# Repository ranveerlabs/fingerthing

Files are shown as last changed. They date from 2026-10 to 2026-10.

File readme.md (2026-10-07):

# fingerthing

i wanted touchid but too broke for a maccc

USB fingerprint security key for passkeys and 2FA. RP2350, a 3.3 V R503 sensor
and [pico-fido2](https://github.com/librekeys/pico-fido2) firmware.

fingerthing board front

## why

I want fingerprint approval for my npm account and other FIDO2 sites, using
the same key across laptops. Linux, Windows, macOS and
[FreeBSD](host/freebsd/readme.md) are targets. sudo through PAM is another target.

## the key

The sensor matches on-chip and sends the result over UART. A fresh match
approves user presence. FIDO PIN handles verification and allows button
fallback. The fingerprint never sets UV, and UART matches can be spoofed.

Pico 2 comes first for bring-up. The custom board has USB-C, switched sensor
power, a separate presence button, BOOTSEL, a status LED and SWD pads.

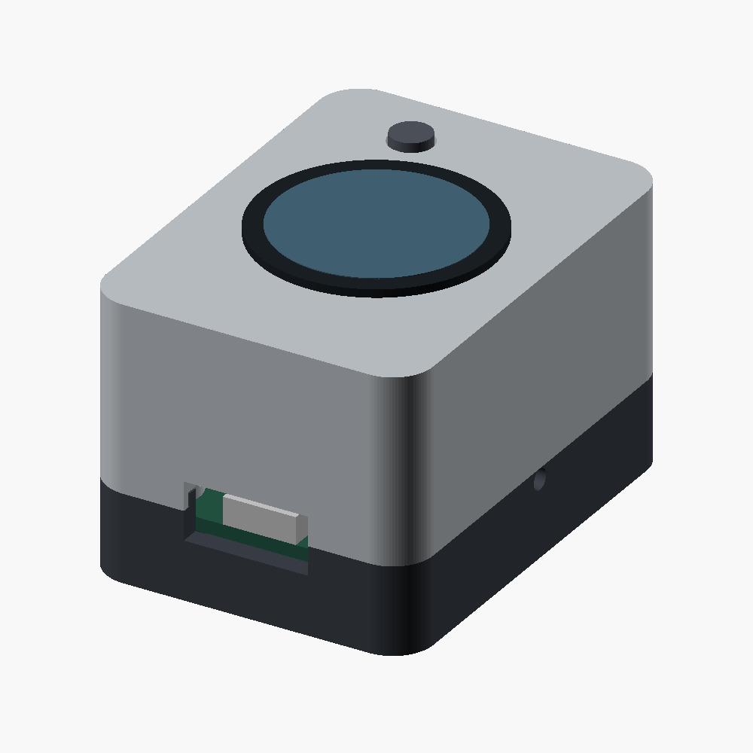
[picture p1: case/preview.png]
fingerthing case design


## build and test

The [firmware guide](firmware/Readme.md) lists the tools and image paths.
Use a dedicated development board. Signing firmware locks OTP storage on
first boot, and reflashing cannot undo that.

```sh
bash firmware/test.sh
bash firmware/build.sh button
bash firmware/build.sh sensor
bash firmware/build.sh pcb
```

[Parts](docs/BOM.md) and [bring-up steps](docs/bringup.md) cover wiring and
enrollment. [Hardware notes](hardware/DESIGN.md) cover the board and sensor.

## status

The 34 x 48 mm four-layer PCB is routed. ERC, DRC and schematic parity pass
with no violations or unconnected items. Firmware builds and host tests pass.
Nothing has been tested on hardware. npm, sudo and OS compatibility remain
unverified. USB power, secure boot and [case fit](case/ReadMe.md) still need
physical tests. The PCB and case are drafts.

Changes and test results are in the [journal](JOURNAL.md).

## license

[CERN-OHL-S-2.0](LICENSE). Firmware is [AGPL-3.0-only](firmware/LICENSE),
including the pico-fido2 patches. Third-party files retain their own licenses :p

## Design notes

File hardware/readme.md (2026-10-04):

# hardware

[Build plan](DESIGN.md) · [KiCad draft](pcb/Readme.md)
Pico 2 bring-up first. The custom board is not ready to order.

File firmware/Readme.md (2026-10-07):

# firmware

[librekeys/pico-fido2](https://github.com/librekeys/pico-fido2) on Pico 2.
Pinned sources. Git, CMake 3.24+, Make, ARM GCC with Newlib, native C compiler,
Python 3. Pico SDK and picotool use 2.3.1. Each configure clears the CMake cache
so an older SDK cannot remain selected. UF2 paths stay the same.

After building all three signing images, `python3 firmware/tests/seal.py` uses
OpenSSL and picotool to check offline signing with a temporary test key. It
also checks that changing application bytes fails verification. The temporary
key and images are removed. This does not provision OTP or enable secure boot.

Supply your own secp256k1 PEM key for a signed build:

```sh
SIGNING_KEY=/absolute/path/private.pem bash firmware/build.sh pcb
```

All modes accept it. Outputs go to the usual directory with `-signed` appended,
such as `.build/pcb-signed/pico_fido2.uf2`. The SDK also creates an OTP JSON plan
containing the public-key hash and boot flags. Building never applies that plan.
Keep the private key outside the checkout and back it up. Fuse provisioning,
signed updates and recovery must be checked on a dedicated A4 board first.
Check a built image against its key with:

```sh
python3 firmware/tests/signed.py /absolute/path/private.pem .build/pcb-signed/pico_fido2.uf2
```

```sh
bash firmware/build.sh
bash firmware/build.sh sensor
bash firmware/build.sh pcb
bash firmware/build.sh enroll
bash firmware/build.sh enroll-pcb
```

UF2: `.build/pico2/pico_fido2.uf2` or `.build/sensor/pico_fido2.uf2`.
The custom board build is `.build/pcb/pico_fido2.uf2`. It uses an active-low
button on GP6 with a 20 ms debounce. BOOTSEL stays available for recovery.
GP8 powers the sensor for each approval attempt and turns it off afterward.
GP4 and GP5 return to inputs without pulls before power-off. The Pico 2 sensor
build leaves power wiring unchanged. Both wait 250 ms before enabling UART,
with cancellation and PIN fallback available during startup.
BOOTSEL while plugging in, then copy the UF2. Use a dedicated development board:
upstream writes and locks OTP keys on first boot. Reflashing cannot undo this.

Flash writes stop the device if the other core cannot be paused or resumed
after five attempts. Both erase paths mask interrupts. This avoids proceeding
after a failed handshake. Reset is required after that failure, and writes
already completed cannot be undone.

Button: fresh press and release. Sensor: fresh match in slot 0, one attempt per
request. Button fallback requires a verified PIN for that request. Both time out
after 30 seconds. Fingerprint approval never sets UV. OTP, OATH and debug output
are disabled. Secure boot is not enabled.

The inherited USB rescue app is unregistered. Its host commands cannot change
boot fuses, reboot into BOOTSEL or sign with the device rescue key. Recovery
uses the physical BOOTSEL control. OTP key initialization on first boot remains.

The signing builds declare 100 mA USB power. Actual draw and USB suspend are
unverified, see [power](../hardware/power.md).

The separate [power probe](power/Readme.md) builds with `bash firmware/build.sh power`.

Approval starts only while USB is configured and awake. Suspend, disconnect or
reconfiguration cancels pending button and fingerprint approval, including PIN
fallback. Resuming does not clear that cancellation. Request cleanup turns off
the PCB sensor. MCU sleep and physical suspend timing remain unverified.

R503: 3.3V and GND, sensor RX to GP4, TX to GP5. UART1, 57600 baud.
Enrollment: flash `.build/enroll/enroll.uf2` with BOOTSEL, open its USB serial
port, type `e`, then `y`. Lift and scan the same finger twice. Esc cancels.
This development image replaces slot 0 and has a 60-second timeout. Flash the
sensor firmware afterward. Use it before storing credentials. Enrollment has no FIDO code. Signing firmware has no enrollment command.

For the switched PCB, use `.build/enroll-pcb/enroll.uf2`, then the `pcb` signing
image. Enrollment powers the sensor only after `y` and turns it off when the
attempt ends. The plain `enroll` image does not control GP8.

Suspend, disconnect or reconfiguration cancels the pending enrollment and its
confirmation prompt. Resume does not clear it. Start again with `e`, then `y`.
Closing the serial connection's DTR line cancels it too.
Cancellation cannot undo a store command already sent, so slot 0 may have changed
even if the image reports failure.

UART matches can be spoofed. Enrollment has not been tested on hardware.

Builds and host tests pass. No hardware, npm or FreeBSD test yet.

## license

[AGPL-3.0-only](LICENSE). Upstream firmware and its dependencies retain their
own license notices.

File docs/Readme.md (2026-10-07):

# docs

[Parts](BOM.md) · [bring-up](bringup.md) · [hardware](../hardware/DESIGN.md) · [journal](../JOURNAL.md)

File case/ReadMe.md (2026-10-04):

# case

case

Rounded two-piece shell, USB-C at the front, screws underneath. The body is
39.4 x 53.4 x 33 mm around the 34 x 48 mm PCB. The sensor and button project
above it. [immurok](https://github.com/immurok/hardware) was a packaging reference.

[source](fingerthing.scad) and [parts](parts/) use millimetres. OpenSCAD 2021.01
exports the base upright, lid upside down and button upright:

```sh
for part in base lid button; do
    openscad -D "part=\"$part\"" --export-format binstl -o "case/parts/$part.stl" case/fingerthing.scad
done
```

The board sits 7 mm above the bottom. Four M2.5 x 10 screws pass through its
mounting holes into nuts in the lid. Nut pockets are 5.3 mm across flats and
2.4 mm deep. Screw head recesses are 5.2 mm wide and 2.4 mm deep. Use hardware
that fits these pockets, without washers against components.

Fit the sensor through the 25.5 mm opening and secure it with its supplied nut.
Insert the button from inside the lid, then the four nuts. Connect the sensor
cable before seating the board on the base supports and closing the shell.
BOOTSEL and SWD require opening the case. A side hole faces the status LED.

The [documented R503](../hardware/sensor.md) is 28 mm wide and 19 mm tall.
Its flange and nut are only approximate in the assembly view. The PCB and
component blocks in that view are clearance guides, not complete board models.

The three meshes are closed single pieces. Geometry checks cover the shell
joint, button at rest and 0.6 mm down, sensor opening and the board guides.
These checks do not prove that the supplied module, cable or USB plug fits.
Measure those before printing. Print a fit sample before committing to the shell.

`sensor_hole`, `fit`, `pcb_z` and `button_gap` adjust the fit. The switch's
[specified height](https://www.we-online.com/components/products/datasheet/434133025816.pdf)
is 2.5 mm. The default button gap is 0.35 mm. Check that it releases fully and
does not preload the switch before storing credentials. Print tolerances and
button travel still need a physical check.

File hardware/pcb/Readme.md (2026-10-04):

# pcb

KiCad 10. 34 x 48 mm, four layers, rounded corners. RP2350A, USB-C, R503 header,
GP6 presence button and rear SWD connector. All nets are routed. ERC, DRC and
board/schematic parity pass with no exclusions.

USB targets 90 ohms on JLC04161H-7628. The coupled section uses 0.235 mm traces,
0.15 mm spacing and 0.25 mm clearance to the ground fill. JLCPCB's calculator
returned 0.2347 mm for those inputs on 2026-10-04.

Copper and dielectric thicknesses follow that stackup: 0.035 mm outer copper,
0.0152 mm inner copper, 0.2104 mm prepreg and a 1.065 mm core. Solder-mask and
material-property fields remain nominal. Connector joins and ESD fan-out are
not fully coupled. Final fabrication review and hardware testing remain.

J1 is JAE DX07S016JA1R1500. The local KiCad footprint grounds both shell
reinforcement pads and removes the edge silk markers. Flash, crystal and core
regulator routing come from Raspberry Pi's RP2350A R4/S1 reference. C20 adds a
100 nF VBUS bypass beside the ESD protector's supply via.

R503 cable fit and the enclosure are not confirmed. Do not order this yet.
`bash hardware/check.sh` runs ERC and DRC with KiCad's standard libraries installed.

[BOM](bom.csv): 47 fitted components. R1 is DNP. U2 is AP2112K-3.3TRG1,
with C1 and C5 beside its input and output. Suspend handling and current
measurements remain, see [power](../power.md).

U5 is TPS22919DCKR. GP8 switches both R503 supplies. C21 bypasses the input,
C22 bypasses the output, R15 pulls ON down and R16 pulls sensor RX up to the
switched rail. The `pcb` and `enroll-pcb` images control the switch, with physical
power and backfeed tests still pending.
The UART pull-up branch uses In1.Cu below the USB routing.

The [local switch symbol](fingerthing.kicad_sym) comes from KiCad's
[Power_Management library](https://gitlab.com/kicad/libraries/kicad-symbols/-/blob/master/Power_Management.kicad_sym).
QOD has a passive pin type because TI specifies tying it to OUT. [license](LICENSE.kicad)

[reference](https://datasheets.raspberrypi.com/rp2350/Minimal-KiCAD.zip) · [license](LICENSE.raspberrypi)

[USB footprint](https://gitlab.com/kicad/libraries/kicad-footprints/-/blob/master/Connector_USB.pretty/USB_C_Receptacle_JAE_DX07S016JA1R1500.kicad_mod) · [license](LICENSE.kicad)

[impedance calculator](https://jlcpcb.com/pcb-impedance-calculator) · [stackup](https://jlcpcb.com/impedance) · [ESD layout](https://www.st.com/resource/en/datasheet/usblc6-2.pdf)

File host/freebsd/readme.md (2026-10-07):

# FreeBSD

Target: npm 2FA in Firefox, using the same USB firmware. Not tested yet.

The upstream firmware uses USB ID `1d50:619b`. Check with `usbconfig` before
installing the rule. It grants the `u2f` group access to matching `uhid` and
`hidraw` devices.

As root, from the repo:

```sh
pkg install firefox libfido2 u2f-devd
pw groupmod u2f -m YOUR_USER
install -m 644 host/freebsd/fingerthing.conf /usr/local/etc/devd/fingerthing.conf
service devd restart
```

Replace `YOUR_USER`, log out and back in, then reconnect the key. Run
`fido2-token -L` as that user. Test enrollment, sign-in and reconnect in Firefox
before trying npm. Record the FreeBSD, Firefox and firmware versions.

If the key is missing from the list, inspect its device node and permissions.
Don't grant access to every USB device or run the browser as root.

Based on FreeBSD's [u2f-devd rules](https://github.com/freebsd/freebsd-ports/tree/main/security/u2f-devd).
[libfido2](https://github.com/Yubico/libfido2/blob/main/src/hid_freebsd.c)
prefers `hidraw`, then falls back to `uhid`. FreeBSD's
[HID bus](https://github.com/freebsd/freebsd-src/blob/main/sys/dev/hid/hidbus.c)
reports the vendor and product IDs used by this rule.

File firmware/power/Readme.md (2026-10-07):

# power probe

```sh
bash firmware/build.sh power
```

Flash `.build/power/power.uf2` on a dedicated Pico 2 before storing credentials.
It replaces the running firmware. It has USB serial, no FIDO code and no OTP
provisioning. Reflashing does not undo OTP locks from an earlier signing image.
First measure with the sensor disconnected.

All images pin Pico SDK and picotool 2.3.1.
On USB suspend it switches the system and peripheral clocks to the crystal
reference, turns off PLL_SYS and sleeps until an interrupt. USB clocks and the
timer remain enabled. Resume restores the system clock.
The suspend snapshot, sensor switch and clock transition now share the same
IRQ mask as the sleep decision. This closes a window that could leave PLL_SYS
running while the probe slept. Host tests inject suspend at that boundary.

GP8 starts low and goes high only while USB is configured and awake. It drives
the ON input of the [sensor switch](../../hardware/power.md#sensor-switch),
not the sensor supply. GP4, GP5 and GP7 stay inputs with no pulls. This image
sends no UART commands.

Open USB serial and send `?`. The reply reports the configured system frequency
in Hz, not a measurement. Trigger actual USB bus suspend, then resume and send
`?` again. Check that serial returns without a reset or re-enumeration.

Measure VBUS current with a low-burden probe that preserves USB data. Capture
suspend entry and resume. Check the 2.5 mA suspend limit and 7 ms transition
in [the power notes](../../hardware/power.md). A sleeping computer alone does
not prove its USB port suspended this device.

The SDK serial descriptor declares 250 mA. This is a budget, not measured draw.
The image builds with warnings treated as errors. No physical power or wake
test yet. The switch is in the draft PCB. Signing firmware controls it per request.

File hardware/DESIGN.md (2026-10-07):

# hardware

Pico 2 for bring-up. Get registration and sign-in working with pico-fido2 and the
button before adding a fingerprint sensor. npm is the first real-service test.

## sensor

Use the 3.3 V R503 variant in [the sensor notes](sensor.md). Match on the module,
send the result over UART. Confirm the supplier's variant and cable before ordering.

A fresh match can gate user presence. It must not set FIDO's UV flag by itself.
Keep the upstream PIN path. Fingerprint UV needs enrollment authorization,
retry limits, reset handling and CTAP integration. PIN fallback does not prevent
someone injecting a fake match on the UART wires.

## board

- RP2350A, 12 MHz crystal, QSPI flash. Start from Raspberry Pi's reference circuit.
- USB-C, separate 5.1k CC pull-downs, ESD protection, 90 ohm differential routing.
- 3.3 V supply plus the RP2350 core regulator circuit and reference decoupling.
- Sensor connector, BOOTSEL, status LED and SWD pads.
- Separate presence button on GP6, pulled up to 3.3 V through 10k.
- Four layers preferred. Assembly service for the QFN.

The [BOM](pcb/bom.csv) selects parts, but assembly stock is not confirmed.
AP2112K-3.3TRG1 supplies 3.3 V. [USB suspend](power.md) still needs firmware and
measurements. USB series termination follows the RP2350 reference. The core
supply needs more than an external 3.3 V LDO.

OTP is storage, not automatic key protection. Secure boot, debug restrictions,
key provisioning and silicon revision all matter. Upstream initializes and locks key storage on first boot. Use a dedicated
bring-up board. Secure-boot provisioning waits until updates and recovery work.

Require A4 silicon for the final board and confirm the chip marking.
[A4 fixes](https://www.raspberrypi.com/news/rp2350-a4-rp2354-and-a-new-hacking-challenge/)
include GPIO leakage and boot ROM and OTP security defects. A generic RP2350A
part number does not establish the stepping. SDK and picotool are pinned to
2.3.1. A4 hardware checks and secure boot remain.

## references

- [immurok hardware](https://github.com/immurok/hardware), reference for sensor clearance,
  separate service controls and labeled pads. Its USB-C is charging-only.
- [RP2350 design files and hardware guide](https://pip.raspberrypi.com/categories/1214-rp2350)
- [RP2350 security features](https://pip-assets.raspberrypi.com/categories/1260-security/documents/RP-009377-WP-1-Understanding%20RP2350_s%20security%20features.pdf)
- [npm security-key setup](https://docs.npmjs.com/configuring-two-factor-authentication/)

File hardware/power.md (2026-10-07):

# power

Signing firmware declares a 100 mA USB budget. The inherited descriptor declared
2 mA. Neither value is a measurement. Check draw before configuration, during
registration and signing, with the sensor lit and during suspend.

U2 is AP2112K-3.3TRG1. Its [datasheet](https://www.diodes.com/assets/Datasheets/AP2112.pdf)
specifies 55 uA typical and 80 uA maximum idle current at 4.3 V input with
no load. It replaces the NCP1117. These figures do not include the rest of the board.

Enable is tied to VBUS. Pin 4 is unconnected. C1 and C5 are 10 uF ceramic
capacitors beside the input and output. Check inrush and VBUS dip at plug-in,
as well as steady current and regulator temperature in the closed case.

[TinyUSB's suspend callback](https://github.com/hathach/tinyusb/blob/0.18.0/src/device/usbd.h)
requires less than 2.5 mA average bus draw within 7 ms. The callback cancels
pending approval. PCB request cleanup releases UART and cuts sensor power.
MCU sleep, transition timing and whole-board measurements remain.

Signing runs on the second core and flash writes run on the USB core. Sleep
must wait for pending work and preserve the flash handshake. The signing
patch stops the device on a failed handshake. This is not suspend support.

The [power probe](../firmware/power/Readme.md) tests MCU clock reduction on a
Pico 2, then sensor switching with an external circuit. The draft PCB now
switches both R503 supplies with GP8. The `pcb` signing image powers the sensor
for each request and turns it off afterward.
Backfeed checks and physical power measurements remain.

Check the chip stepping during bring-up. A2 GPIO leakage can affect inputs
even with pulls disabled. Require A4 for the final board, as described in the
[hardware notes](DESIGN.md).

Do not order the custom board until these changes and checks are complete.

## sensor switch

U5 is [TPS22919DCKR](https://www.ti.com/lit/ds/symlink/tps22919.pdf), SC-70-6.
Checked the datasheet's top-view pin drawing. The same connections apply to
an external prototype circuit on Pico 2.

| Switch pin | Connection |
| --- | --- |
| 1 IN | Pico 2 3V3, 1 uF ceramic to ground beside the switch |
| 2 GND | Common ground |
| 3 ON | GP8, 100k to ground |
| 4 NC | Unconnected |
| 5 QOD | Pin 6 OUT |
| 6 OUT | R503 pins 1 and 6, 100 nF ceramic to ground |

Power both sensor supplies through the switch. Touch wake is unused. Connect
sensor TX to GP5 and RX to GP4. Put 10k from sensor RX to the switched supply,
so RX stays high while the probe leaves GP4 as an input. GP7 may connect to
finger detection. Check cable pin order first.

The probe disables the switch at startup, USB suspend and disconnect. Measure
the switched rail voltage and VBUS draw with power off, then check inrush when
it turns on. Include the sensor's internal capacitance. The signing image waits
250 ms before enabling UART and releases both pins before power-off. Test cold
startup, rapid repeated requests and cancellation during startup on the exact
sensor variant. No physical power-cycle tests yet.

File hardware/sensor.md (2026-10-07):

# sensor

The board follows GROW's R503 manual, 2019.6 version 1.1: 3.3 V power and UART,
28 mm outside diameter, M25 thread, 23.5 mm inner diameter and 19 mm height.
Selected supplier: [Adafruit #4651](https://www.adafruit.com/product/4651),
which specifies 3.3 V power, TTL UART and 57600 baud by default.
Its listing says 15.5 mm height, while its linked GROW manual says 19 mm.
The case retains the 19 mm clearance guide. Measure the received module,
thread, flange, nut and cable before printing.

| Sensor pin | Function | J2 connection |
| --- | --- | --- |
| 1 | 3.3 V power | SENSOR_3V3 |
| 2 | Ground | GND |
| 3 | TXD | GP5, MCU RX |
| 4 | RXD | GP4, MCU TX |
| 5 | Finger detection | GP7 |
| 6 | Touch supply | SENSOR_3V3 |

U5 switches both supplies with GP8. R15 keeps the switch off at reset.
R16 pulls sensor RX up to the switched rail. Touch wake is unused.
The `pcb` signing and `enroll-pcb` development images control GP8. UART pins
return to inputs without pulls before cutting sensor power. This needs a
physical backfeed and power-cycle check.

UART defaults to 57600 baud, 8N1. J2 uses JST SH at 1.0 mm pitch. The manual calls
the sensor connector MX1.0-6P. Use a pin-for-pin adapter cable, with each plug
matched to its socket. Verify pin 1 and continuity before applying power.
For Pico 2 bring-up, use the supplied sensor cable with soldered breadboard
header pins. Do not force its plug into J2.

[manufacturer manual](https://download.mikroe.com/documents/datasheets/R503_datasheet.pdf)

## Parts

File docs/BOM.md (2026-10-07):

# parts

| part | quantity | status |
|---|---:|---|
| [Pico 2, Adafruit #6006](https://www.adafruit.com/product/6006) | 1 | development board, solder two 20-pin headers |
| [USB A to micro-B data cable, #592](https://www.adafruit.com/product/592) | 1 | for Pico 2 |
| [3.3 V R503, #4651](https://www.adafruit.com/product/4651) | 1 | UART, supplied sensor cable |
| [830-point breadboard, #239](https://www.adafruit.com/product/239) | 1 | prototype wiring |
| [Male/male jumpers, #759](https://www.adafruit.com/product/759) | 1 pack | breadboard connections |

These are bring-up parts. Adafruit's Pico 2 listing still specifies A2 silicon.
Use it for development only. Require A4 for the final board and verify the chip
marking before provisioning. [A4 fixes GPIO leakage and several security defects](https://www.raspberrypi.com/news/rp2350-a4-rp2354-and-a-new-hacking-challenge/).
The builds use SDK and picotool 2.3.1. A4 hardware checks and secure boot remain.

The sensor cable needs soldered 2.54 mm header pins for the breadboard. Check
pin numbers with the [sensor notes](../hardware/sensor.md), not wire colours.
Its plug is not verified as compatible with the PCB's JST SH socket.

The final board uses USB-C. Nothing ordered yet. A soldering iron, solder,
wire stripper and multimeter are needed for this prototype.
Follow the [bring-up steps](bringup.md) after the parts arrive.

The [board BOM](../hardware/pcb/bom.csv) comes from the schematic. It lists
47 fitted components with manufacturer part numbers. R1 is DNP and the four
mounting holes are excluded. Assembly stock has not been confirmed.

The board uses AP2112K-3.3TRG1 for 3.3 V. USB suspend and current measurements
still need work. Sensor and enclosure fit remain unverified. Do not use this
BOM to order a board yet.

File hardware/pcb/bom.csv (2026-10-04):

refs | value | manufacturer | mpn | footprint | quantity
C1,C5,C19 | 10u | Murata | GRM21BR61C106KE15L | RPI_COMPILED:generic_capc2012x125 | 3
C2,C8,C10-C18,C20,C22 | 100n | Murata | GRM155R71E104KE14D | RPI_COMPILED:generic_capc1005x50 | 13
C3,C4 | 15p | Murata | GRM1555C1H150JA01D | RPI_COMPILED:generic_capc1005x50 | 2
C6,C7 | 4.7u | Murata | GRM155R60J475ME47D | RPI_COMPILED:generic_capc1005x50_wide | 2
C9 | 4.7u | Murata | GRM155R60J475ME47D | RPI_COMPILED:generic_capc1005x50 | 1
C21 | 1u | TDK | C1005X5R1E105K050BC | Capacitor_SMD:C_0402_1005Metric | 1
D1 | green | Lite-On | LTST-C190KGKT | LED_SMD:LED_0603_1608Metric | 1
J1 | DX07S016JA1R1500 | JAE | DX07S016JA1R1500 | fingerthing:usb-c | 1
J2 | R503 | JST | SM06B-SRSS-TB(LF)(SN) | Connector_JST:JST_SH_SM06B-SRSS-TB_1x06-1MP_P1.00mm_Horizontal | 1
J4 | SM03B-SRSS-TB(LF)(SN) | JST | SM03B-SRSS-TB(LF)(SN) | RPI_COMPILED:jst_sm03b-srss-tb-lf--sn- | 1
L1 | 3.3u | Abracon | AOTA-B201610S3R3-101-T | RPI_COMPILED:abracon_aota-b201610s3r3-101-t | 1
R2,R6 | 1k | Yageo | RC0402FR-071KL | RPI_COMPILED:generic_resc1005x35 | 2
R3 | 33 | Yageo | RC0402FR-0733RL | RPI_COMPILED:generic_resc1005x35 | 1
R7,R8 | 27 | Yageo | RC0402FR-0727RL | RPI_COMPILED:generic_resc1005x35 | 2
R10 | 0 | Yageo | RC0402JR-070RL | RPI_COMPILED:generic_resc1005x35 | 1
R11,R12 | 5.1k | Yageo | RC0402FR-075K1L | Resistor_SMD:R_0402_1005Metric | 2
R13 | 1k | Yageo | RC0402FR-071KL | Resistor_SMD:R_0402_1005Metric | 1
R14,R16 | 10k | Yageo | RC0402FR-0710KL | Resistor_SMD:R_0402_1005Metric | 2
R15 | 100k | Yageo | RC0402FR-07100KL | Resistor_SMD:R_0402_1005Metric | 1
SW1,SW3 | 434133025816 | Wurth Elektronik | 434133025816 | RPI_COMPILED:wurthelek_434133025816 | 2
U1 | RP2350A | Raspberry Pi | RP2350A | RPI_COMPILED:rpi_rp2350a_vias | 1
U2 | AP2112K-3.3 | Diodes Incorporated | AP2112K-3.3TRG1 | Package_TO_SOT_SMD:SOT-23-5 | 1
U3 | W25Q128JVSIQ | Winbond | W25Q128JVSIQ | RPI_COMPILED:generic_soic127p790x195-8 | 1
U4 | USBLC6-2SC6 | STMicroelectronics | USBLC6-2SC6 | Package_TO_SOT_SMD:SOT-23-6 | 1
U5 | TPS22919DCK | Texas Instruments | TPS22919DCKR | Package_TO_SOT_SMD:SOT-363_SC-70-6 | 1
X1 | 12MHz | Abracon | ABM8-272-T3 | RPI_COMPILED:generic_xtalcc320x250x80-4 | 1

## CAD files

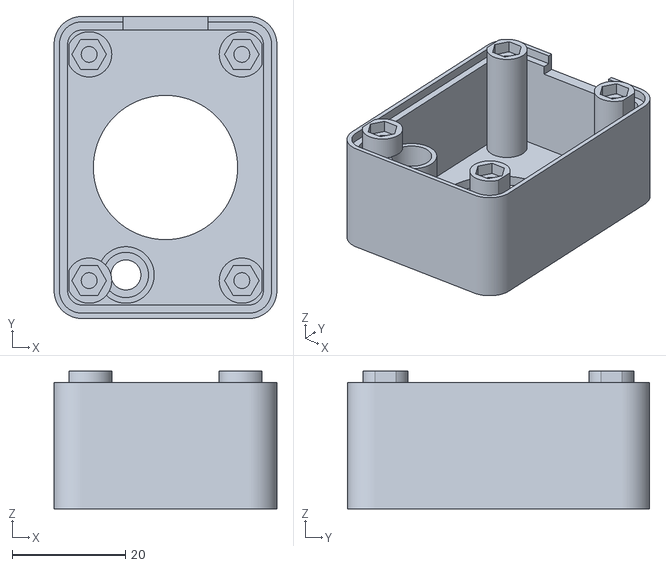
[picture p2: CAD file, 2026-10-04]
case/parts/lid.stl
39.4 x 53.4 x 24.4

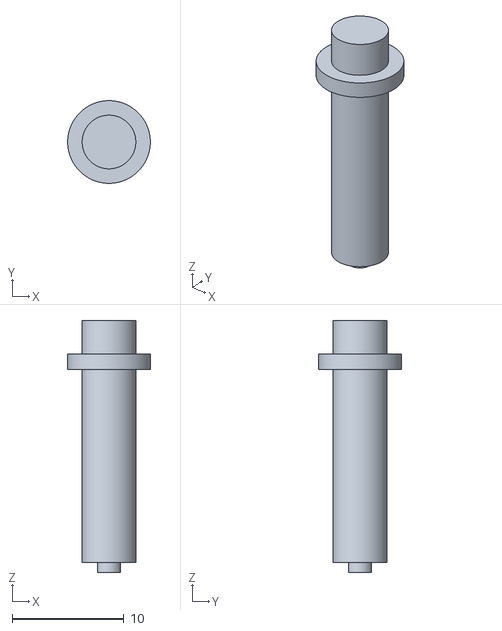
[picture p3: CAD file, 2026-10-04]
case/parts/button.stl
7.40 x 7.40 x 22.5

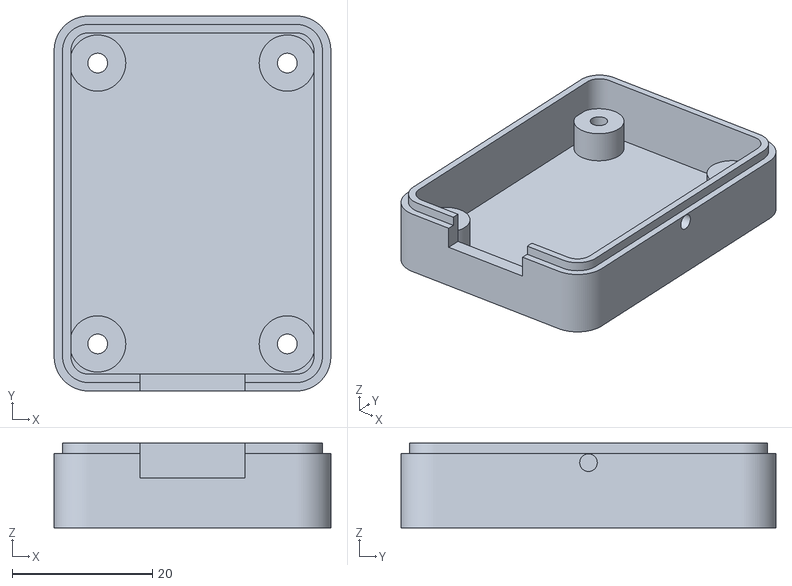
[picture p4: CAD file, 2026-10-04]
case/parts/base.stl
39.4 x 53.4 x 12.1

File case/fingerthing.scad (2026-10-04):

part = "assembly";
pcb_z = 7;
pcb_t = 1.6;
height = 33;
joint = 10.6;
sensor_hole = 25.5;
button_gap = 0.35;
fit = 0.25;
lid_alpha = 1;
$fn = 96;

holes = [[3.5, 4], [30.5, 4], [3.5, 44], [30.5, 44]];
button_z = pcb_z + pcb_t + 2.5 + button_gap;

assert(pcb_z > 5 && height - 19 > pcb_z + pcb_t + 2);
assert(button_gap >= 0.2 && button_gap <= 0.6);
assert(fit >= 0.15 && fit <= 0.4);
assert(part == "base" || part == "lid" || part == "button" || part == "assembly");

module outline(inset = 0) {
    translate([17, 24])
        offset(r = 4.9 - inset)
            square([29.6, 43.6], center = true);
}

module shell(z, h, inset = 2.4) {
    translate([0, 0, z]) linear_extrude(h)
        difference() {
            outline();
            outline(inset);
        }
}

module port() {
    translate([9.5, -4, pcb_z + 0.1]) cube([15, 6, 7]);
}

module base() {
    difference() {
        union() {
            linear_extrude(2) outline();
            shell(1.9, joint - 1.9);
            translate([0, 0, joint - 0.1]) linear_extrude(1.6)
                difference() {
                    outline(1.2);
                    outline(2.4);
                }
            for (p = holes)
                translate([p[0], p[1], 1.9]) cylinder(d = 8, h = pcb_z - 1.9);
        }
        for (p = holes) {
            translate([p[0], p[1], -0.1]) cylinder(d = 2.8, h = pcb_z + 0.2);
            translate([p[0], p[1], -0.1]) cylinder(d = 5.2, h = 2.5);
        }
        port();
        translate([29, 24, pcb_z + pcb_t + 0.7]) rotate([0, 90, 0]) cylinder(d = 2.5, h = 9);
    }
}

module lid() {
    difference() {
        union() {
            shell(joint, height - joint);
            translate([0, 0, height - 2]) linear_extrude(2) outline();
            intersection() {
                translate([0, 0, pcb_z + pcb_t]) linear_extrude(height - pcb_z - pcb_t)
                    outline(2.4 + fit);
                union() for (p = holes)
                    translate([p[0], p[1], pcb_z + pcb_t])
                        cylinder(d = 8, h = height - pcb_z - pcb_t);
            }
            translate([10, 43, button_z + 1.5])
                cylinder(d = 10, h = height - 2 - button_z - 1.5 + 0.1);
        }
        translate([0, 0, joint - 0.1]) linear_extrude(1.6 + fit)
            difference() {
                outline(1.2 - fit);
                outline(2.4);
            }
        for (p = holes) {
            translate([p[0], p[1], pcb_z + pcb_t - 0.1]) cylinder(d = 2.8, h = 9.6);
            translate([p[0], p[1], pcb_z + pcb_t - 0.1])
                cylinder(d = 5.3 / cos(30), h = 2.4, $fn = 6);
        }
        translate([17, 24, height - 2.1]) cylinder(d = sensor_hole, h = 2.2);
        translate([10, 43, height - 2.1]) cylinder(d = 5.3, h = 2.2);
        translate([10, 43, button_z + 1.4])
            cylinder(d = 8, h = height - 2 - button_z - 1.4);
        port();
    }
}

module button() {
    translate([10, 43, button_z]) union() {
        cylinder(d = 2.1, h = 1);
        translate([0, 0, 0.9]) cylinder(d = 4.8, h = height + 1 - button_z - 0.9);
        translate([0, 0, height - 3.4 - button_z]) cylinder(d = 7.4, h = 1.4);
    }
}

module board() {
    color([0.13, 0.32, 0.25]) translate([17, 24, pcb_z])
        linear_extrude(pcb_t) offset(r = 2) square([30, 44], center = true);
    color("silver") translate([12.6, 0, pcb_z + pcb_t]) cube([8.8, 7, 3.3]);
    color("black") translate([7.5, 43 - 1.6, pcb_z + pcb_t]) cube([5, 3.2, 2.5]);
    color("black") translate([6, 13, pcb_z + pcb_t]) cube([8, 5, 2]);
    color("ivory") translate([4, 17, pcb_z - 3]) cube([8, 5, 3]);
    color("ivory") translate([23, 33, pcb_z - 3]) cube([5, 6, 3]);
}

module sensor() {
    color("silver") translate([17, 24, height - 17.9]) cylinder(d = 25, h = 17.9);
    color([0.1, 0.12, 0.14]) translate([17, 24, height]) cylinder(d = 28, h = 1);
    color([0.25, 0.38, 0.45]) translate([17, 24, height + 1]) cylinder(d = 23.5, h = 0.1);
}

if (part == "base") base();
if (part == "lid") translate([0, 0, height]) rotate([180, 0, 0]) lid();
if (part == "button") translate([-10, -43, -button_z]) button();
if (part == "assembly") {
    color([0.22, 0.24, 0.27]) base();
    color([0.72, 0.74, 0.76], lid_alpha) lid();
    color([0.3, 0.32, 0.35]) button();
    board();
    sensor();
}

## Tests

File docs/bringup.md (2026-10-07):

# bring-up

Start with the [parts list](BOM.md) and a dedicated development board. Nothing
has been tested on hardware. The signing firmware locks OTP storage on first
boot, and reflashing cannot undo that.

1. Solder the Pico 2 headers and the supplied sensor cable's breadboard pins.
   Leave the sensor disconnected. Build and flash the
   [power probe](../firmware/power/Readme.md). Check USB serial, suspend and resume.
2. Build the button image with `bash firmware/build.sh button`. Hold BOOTSEL
   while plugging in, then copy `.build/pico2/pico_fido2.uf2`. Check that
   `fido2-token -L` finds it. Use BOOTSEL for a fresh press and release when
   requested. Test registration, sign-in and reconnect with a disposable
   WebAuthn credential before adding the sensor.
3. Unplug USB. Connect the 3.3 V R503 using the table below. Verify cable
   continuity and pin order. Leave its finger-detection wire insulated.
4. Build and flash `enroll`, open USB serial, then type `e` and `y`. Lift and
   scan the same finger twice. Continue only after it reports `saved`.
5. Build and flash `sensor`. Test a matching finger, a different finger,
   cancellation, disconnect during a request and a fresh request after reconnect.
   Test PIN fallback with BOOTSEL too. A match supplies presence, never UV.
6. Once those checks pass, follow [npm's security-key setup](https://docs.npmjs.com/configuring-two-factor-authentication/).
   Name it `fingerthing`, retain another working key and save recovery codes
   separately. Test a fresh sign-in after unplugging and reconnecting it.

| R503 pin | Pico 2 connection | Physical pin |
| --- | --- | --- |
| 1, power | 3V3(OUT) | 36 |
| 2, ground | GND | 8 |
| 3, TXD | GP5, UART1 RX | 7 |
| 4, RXD | GP4, UART1 TX | 6 |
| 5, finger detection | Unconnected | |
| 6, touch supply | 3V3(OUT) | 36 |

Use the [Pico 2 pinout](https://datasheets.raspberrypi.com/pico/Pico-2-Pinout.pdf)
and [sensor pinout](../hardware/sensor.md). This wiring uses constant sensor
power. It does not use the PCB's GP8 switch or the `pcb` firmware profile.

Record the board stepping, sensor variant, firmware commit, OS and browser
versions with each result. Repeat the host checks on FreeBSD using its
[access rule](../host/freebsd/readme.md). Custom-board assembly, switched-power
tests, secure boot and case fit remain separate hardware gates.

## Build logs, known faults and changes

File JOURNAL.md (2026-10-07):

# fingerthing build journal

## session 001 - 2026-09-27

Started the repository with an AGPL-3.0-only license and folders for hardware,
firmware, the case and docs, following the structure of MorphCPU.

The goal is a fingerprint device that can be used as a passkey across laptops
and operating systems. The sensor, controller, connection and credential storage
are still undecided. There is no prototype or compatibility testing yet.

The next step is to work out the passkey requirements and compare parts before
starting the schematic. Fingerprint enrollment, matching, credential storage
and recovery need a design before firmware work starts.

Session time was not recorded.

## session 002 - 2026-09-27

Compared a plug-in security key with a separate fingerprint button. The proposed
first version uses a USB cable so the sensor can sit beside the keyboard. It
would still behave as a security key through CTAP2 over USB HID.

Added [design notes](hardware/DESIGN.md) with the authentication boundary, parts
to evaluate and prototype checks. Reviewed the FIDO CTAP and W3C WebAuthn
specifications. A touch establishes presence, while fingerprint matching or a
PIN provides user verification. Browser passkeys and OS login need separate
compatibility work.

No components were selected or tested. Session time was not recorded.

## session 003 - 2026-09-27

Narrowed the first target to 2FA on my npm account. Checked npm's documentation:
security keys are registered on the website through WebAuthn and can also be
used for CLI authentication. Updated the design with npm registration, fresh
sign-in and the `npm login` browser flow as the first acceptance checks.

Discoverable credentials are still useful for broader passkey support, but
npm's exact WebAuthn requirements have not been observed. No account settings
were changed and no hardware was tested. Session time was not recorded.

## session 004 - 2026-09-30

Switched the build plan to Pico 2 and librekeys/pico-fido2. R503 is the sensor
candidate. Removed the SEN0348 code and enclosure from the active tree, cut the
readmes, and added a FreeBSD USB permission rule. No hardware tests yet.

The upstream startup code writes key material into OTP and locks those pages.
A first flash is not reversible just by replacing the firmware. Secure boot is
a separate step.

## session 005 - 2026-09-30

Built librekeys/pico-fido2 for Pico 2 with SDK 2.1.1. Upstream's button check can
return success before configuration, so this build requires a fresh press and
release. Timeout, cancellation, pre-held button and timer-wrap tests pass.

The UF2 is 873472 bytes. Picotool identifies Pico 2, RP2350 ARM Secure, firmware
7.4 and a verified image hash. Secure boot is not enabled. Nothing flashed yet.

Pinned Mbed TLS to the upstream build's 3.6.5 revision and removed CMake's Git
configuration and dependency-replacement steps.

## session 006 - 2026-10-02

Added R503 packet handling and a fingerprint presence gate. Slot 0 only, fresh
touch, one match attempt per request. Button fallback needs that request's PIN.
Malformed replies, sensor errors, held inputs and cancellation fail closed.
Host tests cover timer wrap and replies arriving after the request timeout.

Registration could skip presence without a PIN. Patched registration and
assertion to check each request, and removed cached verification from registration.
Fingerprint matching does not set UV. Disabled unused OTP, OATH and debug output.
Both Pico 2 builds pass. Picotool verifies the sensor image hash.
Enrollment and hardware tests are still pending. No custom PCB yet.

## session 007 - 2026-10-04

Added a separate USB serial enrollment image. Explicit confirmation, two fresh
captures, slot 0 only. Capture or merge failure does not request a template write.
The signing image has no enrollment command. Enrollment is for development,
before storing credentials.

Shared the UART transport and removed the unused delete command. Host tests cover
RX floods, malformed lengths, late replies, cancellation and timer wrap. Enrollment
and signing builds pass. Nothing tested on hardware yet.

## session 008 - 2026-10-04

Started the KiCad project from Raspberry Pi's RP2350A R4/S1 reference. Included
local symbols, footprints and embedded models, with the original MIT license.
Fixed the regulator tab's ERC pin type and declared the two filtered supply nets.
Mounting-hole drills and positions are unchanged.

ERC and DRC pass with the project rules, including board/schematic parity.
USB-C, the sensor connector and the final layout are still pending. This is a
reference base, not an orderable fingerthing board.

## session 009 - 2026-10-04

Read immurok's hardware notes and board renders. Use sensor clearance and labeled
service pads as layout references. Keep USB FIDO2 for npm. Immurok uses Bluetooth
with companion apps and its USB-C connector only supplies charging power.

Added the custom board build with a separate presence button on GP6 and 20 ms
debounce. BOOTSEL remains the recovery button. Host tests cover held startup,
contact bounce and timer wrap. Custom board and Pico 2 sensor builds pass.
Picotool verifies the custom image hash. No hardware test yet.

## session 010 - 2026-10-04

Replaced the development headers and micro USB with USB-C, CC pull-downs, ESD
protection, a sensor header, GP6 button and status LED. The draft is 34 x 48 mm
with rounded corners and four copper layers. Sensor and SWD connections are
underneath. Kept the reference flash, crystal and core regulator routing.

ERC passes and board/schematic parity has no issues. DRC still reports 88
unconnected items and four USB connector hole-clearance violations. The stackup
is preliminary. Routing, USB impedance, sensor cable fit and physical tests remain.

## session 011 - 2026-10-04

Changed USB-C to JAE DX07S016JA1R1500. The GCT footprint matched its drawing but
left 0.1944 mm between its locator holes and ground pads. Kept the 0.25 mm hole
clearance rule. The local JAE footprint grounds both shell reinforcement pads.

Added ground planes, a 3.3 V plane and supply vias. Removed floating copper.
ERC and schematic parity pass. DRC has 24 unconnected items and no other
violations. USB, sensor, button, LED and SWD routing remain. No hardware test yet.

## session 012 - 2026-10-04

Routed the GP6 presence button, its pull-up and the GPIO25 status LED. Moved one
3.3 V via to leave room for the LED signal. ERC and schematic parity pass.
DRC has 19 unconnected items and no other violations. USB, sensor and SWD
routing remain. The board is still a draft.

## session 013 - 2026-10-04

Routed GP4, GP5 and GP7 to the sensor header and SWD to the rear connector.
The sensor signals use the power layer to pass the retained core regulator
routing. Added a supply bridge where the routes split the 3.3 V fill.

ERC and schematic parity pass. DRC has 14 unconnected USB items and no other
violations. USB routing and impedance, sensor cable fit and hardware tests remain.

## session 014 - 2026-10-04

Connected both USB-C power banks, the ESD supply and regulator input. Routed
CC1 and CC2 to their separate 5.1k pull-downs. Power tracks are 0.5 mm wide.

ERC and schematic parity pass. DRC has eight unconnected USB data items and
no other violations. The data pair and final impedance still need work.

## session 015 - 2026-10-04

Routed USB through the ESD protector and turned it toward the MCU. Joined both
connector orientations and shortened the protector's ground connection.

JLCPCB's calculator returned 0.2347 mm for a 90 ohm coplanar differential pair
on JLC04161H-7628, with 0.15 mm spacing and 0.25 mm ground clearance. Used
0.235 mm and updated the copper and dielectric thicknesses to that stackup.
The connector joins and ESD fan-out are not fully coupled.

ERC, DRC and board/schematic parity pass with zero unconnected items. No
hardware test yet. Final fabrication review, sensor cable fit and enclosure
work remain.

## session 016 - 2026-10-04

Added C20, a 100 nF VBUS bypass beside the ESD protector's supply via, following
ST's layout example. The capacitor sits underneath and has a nearby ground via.
ERC, DRC and schematic parity pass with zero unconnected items.

Reviewed GROW's 2019.6 R503 manual. The board's six-pin mapping matches its
3.3 V variant. Documented the 28 mm diameter, M25 thread and 19 mm height.
The manual names an MX1.0 sensor plug while J2 uses JST SH. The adapter cable
and supplied sensor still need physical verification.

## session 017 - 2026-10-04

Added a rounded two-piece enclosure for the 34 x 48 mm board and documented
R503. The body is 39.4 x 53.4 x 33 mm. It has a separate button plunger,
underside screws and nut pockets. BOOTSEL and SWD require opening the case.

OpenSCAD 2021.01 exports three closed, connected meshes. Checked the shell
joint, sensor opening, board guides and button at rest and 0.6 mm down.
Intersections are empty or shared mounting surfaces without solid overlap.
Rendered the exported meshes. The assembly uses approximate component blocks.

Sensor flange and nut dimensions, cable routing, USB plug clearance and button
release still need measurements and a print fit check. No hardware tests yet.

## session 018 - 2026-10-04

Filled the missing manufacturer part numbers and exported the board BOM from
the schematic. It covers 42 fitted components, with R1 DNP. ERC, DRC and
schematic parity still pass with zero unconnected items. Routing is unchanged.

The inherited signing descriptor declared 2 mA USB power. Changed it to a
100 mA budget. The PCB build and host tests pass. Its compiled descriptor has
bMaxPower 50, in 2 mA units. No current measurement yet.

Found that the NCP1117's idle current budget and missing USB suspend handling
need work before fabrication. Documented the remaining power checks.

## session 019 - 2026-10-04

Replaced NCP1117 with AP2112K-3.3TRG1. Checked the SOT25 pinout and ordering
code against Diodes' datasheet. Enable follows VBUS and pin 4 is unconnected.
Moved C1 and C5 beside the regulator and rerouted their power and ground.
Removed one duplicate VBUS track while changing that connection.

ERC, DRC and schematic parity pass with zero unconnected items. Rendered the
schematic and top copper. Other footprints, pad positions and nets are unchanged.
Updated the BOM. USB suspend, inrush, current and temperature measurements
remain. No hardware tests yet.

## session 020 - 2026-10-04

Added USB callbacks that cancel pending approval on suspend, disconnect and
reconfiguration. Approval rejects an unavailable USB connection at entry and
return. A quick resume or reconnect does not clear an active cancellation.

Host tests cover cancellation during button release, pending PIN fallback and
a successful sensor match. Checked both PIN states and timer wrap. The SDK
patches apply to clean pinned sources and validate on repeated builds.
Button, sensor and custom-board builds pass with the host tests.

These callbacks do not reduce power. MCU and sensor sleep, resume handling
and physical suspend measurements remain.

## session 021 - 2026-10-04

Added a separate USB serial power probe for Pico 2, using pinned SDK 2.3.1.
It switches the system clock to the crystal reference and disables PLL_SYS
during USB suspend. USB and timer clocks remain enabled for wake-up. Resume
restores the system clock. Signing and enrollment keep SDK 2.1.1.

The probe builds with warnings treated as errors. No sensor, current or USB
wake measurements yet. R503 main power is still wired directly to 3.3 V on
the custom board and needs a switch before whole-board suspend testing.

## session 022 - 2026-10-04

Selected TPS22919DCKR for a sensor power prototype and checked its pin drawing.
Documented switched power for both R503 supplies and a pull-up to that rail
on sensor RX. The power probe now drives GP8 only while USB is configured
and awake. UART and finger-detection pins remain inputs without pulls.

The probe builds with warnings treated as errors. The PCB and signing firmware
do not include the switch yet. No physical switching or backfeed test yet.

## session 023 - 2026-10-04

Added TPS22919DCKR to the PCB. GP8 controls both sensor supplies. Added input
and output bypass capacitors, an ON pull-down and a sensor RX pull-up to the
switched rail. QOD connects to OUT as shown in TI's datasheet. The local symbol
uses a passive QOD pin type for that connection.

Moved the new circuit away from the flash routing. The UART pull-up branch
uses In1.Cu below the USB section. ERC, DRC and schematic parity pass with
zero unconnected items. Rendered the copper and schematic. The BOM now lists
47 fitted components.

Signing firmware still needs GP8 control and UART release before running on
the revised board. Switching, backfeed, inrush and suspend remain unmeasured.

## session 024 - 2026-10-04

Added GP8 control to the PCB signing image. Each attempt powers the sensor,
waits 250 ms with cancellation available, then enables UART. Cleanup resets
UART, releases GP4 and GP5 without pulls and turns the sensor off. Pico 2
sensor wiring stays unchanged.

Added an enroll-pcb build. Enrollment powers the sensor after confirmation
and shuts it down when the attempt ends. Host tests cover startup cancellation,
UART release before power-off, timer wrap, refused I/O while off and request
cleanup after approval and failure with both PIN states.

Button, sensor, PCB and both enrollment builds pass. Checked that only the
PCB signing and enrollment builds define the GP8 switch pin. The new enrollment
build's host picotool emitted SDK SHA-512 self-test overread warnings. The same
SDK self-test passes all six SHA-384 and SHA-512 cases under ASan and UBSan.

Physical startup, backfeed, repeated requests and USB suspend timing remain
unverified. MCU sleep is not integrated into signing firmware.

## session 025 - 2026-10-04

Enrollment now keeps cancellation through a quick USB resume or reconnect.
Suspend, disconnect and reconfiguration invalidate the pending e/y prompt and
sensor attempt. Only starting a new prompt clears it.
Dropping the serial connection's DTR line cancels it too, including a quick reopen.

Both enrollment builds pass. Their compiled images contain the USB callbacks.
Host tests run the actual controller through prompt cancellation, interrupted
enrollment, serial flood, timer wrap and a fresh retry. Queued input draining
is bounded at 128 bytes and rejects an overfull prompt. Added a case for cancellation after
storage. Failure after a store command does not prove slot 0 stayed unchanged.
No hardware USB tests yet.

## session 026 - 2026-10-04

Found that upstream flash writes continued after five failed multicore
lockout attempts. Added a helper that stops the device if pausing or resuming
the other core fails. Added interrupt masking to the erase-only path, matching
the existing erase/program path.

Host tests compile the actual patched flash code with mocked hardware. They
cover failed start and end handshakes, success on the fifth attempt, interrupt
masking, preservation of a prior IRQ mask and pending-page state. No flash
erase runs without an acknowledged
pause in those tests. Writes completed before a failed resume cannot be undone.
MCU suspend and physical flash tests remain.

Button, sensor and PCB signing builds pass with the host tests. The patch
applies to the clean pinned SDK file and validates on repeated builds.

## session 027 - 2026-10-06

The PIN shared-secret helper overwrote an ECDH failure with the key-derivation
result. It now returns that failure without running key derivation.
Set-PIN and change-PIN requests now check the authentication tag length before
comparison. Wrong lengths return CTAP2_ERR_PIN_AUTH_INVALID.
The lengths follow [CTAP PIN protocols 1 and 2](https://fidoalliance.org/specs/fido-v2.2-ps-20250714/fido-client-to-authenticator-protocol-v2.2-ps-20250714.html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):
16 and 32 bytes respectively.

Host tests compile the patched helper and both length guards. They cover tag
lengths from 0 through 96, ECDH and key-derivation errors, unchanged output on
failure and cleanup for both protocols. These use mocked cryptography.

Button, sensor and PCB signing builds pass with the host tests. The patch
applies to clean pinned source and validates on repeated builds.
No Pico or signing-firmware USB device is attached here. npm, FreeBSD and
physical checks remain.

## session 028 - 2026-10-06

Selected Adafruit's 3.3 V R503 #4651 and Pico 2 #6006 for bring-up, with a
data cable, breadboard and jumpers. The sensor listing says 15.5 mm height,
while its linked manual says 19 mm. The case keeps its existing clearance
guide until the module can be measured. The supplied cable needs an adapter
for the custom board's JST SH connector.

The Pico 2 listing specifies A2 silicon. It is a development board here.
The final key requires A4, which fixes GPIO leakage and several security
defects. Supplier confirmation, A4 tooling, secure boot and physical tests
remain. No parts ordered.

## session 029 - 2026-10-06

All images now use Pico SDK 2.3.1 at 079c6f39023649b154152db30f1d781e884879bc
and picotool 2.3.1 at 2041936441b48a3cc53ae3da9e805229fe8f4e18. Fresh CMake
configuration removes the old SDK selection. CMake 3.24 or newer is required.
The previous cache accepted a development picotool, so fetching the pinned
commit is now explicit.

Button, sensor, PCB, both enrollment images and the power probe build.
Host tests pass. The new SDK changes the multicore lockout implementation.
The flash patch still checks its return values and refuses a failed pause.

Offline signing with temporary secp256k1 keys verifies all three signing
images. Changing an application byte makes both hash and signature checks
fail. Test keys and signed images are removed afterward. The local picotool
build has no USB support. This check does not provision a device or prove
boot ROM enforcement. Secure boot and physical A4 testing remain.

## session 030 - 2026-10-06

The inherited rescue app exposes an APDU command that programs boot fuses
using a fixed upstream key hash. Its handler has no PIN or presence check.
That app is now unregistered in signing firmware. Physical BOOTSEL recovery
and first-boot OTP key initialization remain.

The build check inspects each signing ELF. FIDO constructors must remain,
while rescue symbols, the remote BOOTSEL handler and the boot-fuse writer
must be absent. Secure-boot provisioning still needs a separate process with
the project's own key and verified update and recovery behavior.

Button, sensor and PCB builds pass with those ELF checks and the host tests.
Offline signing and corruption checks pass on the changed images. The patch
applies to clean pinned source and validates on repeated builds. No hardware
or boot-fuse programming performed.

## session 031 - 2026-10-06

Added SIGNING_KEY for optional signed builds. It must name a readable PEM file
by absolute path. Signed output goes into separate `-signed` directories.
All six profiles build with a temporary secp256k1 test key. Image signatures
verify with that key, and each OTP plan contains its public-key hash and only
the expected boot fields. A prime256v1 key fails signature verification.

Building creates files only. No OTP plan was applied and no device was
provisioned. The private key belongs outside the checkout and needs a backup.
Fuse provisioning and signed update and recovery behavior remain untested.

A normal button build after the signed builds remains unsigned and passes the
host tests. Offline signing and corruption checks pass on the development
images. The temporary private keys were removed.

## session 032 - 2026-10-06

The power probe checked whether to slow the clock before masking interrupts.
Suspend arriving between that check and the mask could put it to sleep with
PLL_SYS still running. The suspend snapshot, sensor switch, clock transition
and sleep decision now run under the same IRQ mask.

The host test runs the actual controller with mocked clocks and USB events.
It injects suspend at the mask boundary and checks clock reduction, sensor off,
resume and reconnect. It fails against the previous source and passes with
the fix. Physical draw and timing remain unmeasured. Signing firmware still
needs MCU suspend integration after the probe is tested on hardware.

The probe builds and the full host suite passes. No USB current measurement
or physical suspend test performed.

## session 033 - 2026-10-06

The FreeBSD access rule now matches `hidraw` as well as `uhid`. libfido2 prefers
hidraw, and the HID bus reports the same vendor and product fields used by the
rule. Access stays limited to USB ID 1d50:619b and the u2f group.

Checked the upstream driver, libfido2 backend and u2f-devd package sources.
The device-name pattern accepts numbered HID nodes and rejects other node
names. No FreeBSD device or npm sign-in test performed.

## session 034 - 2026-10-06

Added the breadboard bring-up sequence and physical Pico 2 pin numbers for the
R503 cable. Checked the mapping against Raspberry Pi's pinout and the UART
source. The sequence starts with the power probe and button image, then adds
enrollment and fingerprint approval before npm setup.

The host suite passes. Hardware tests, final MCU suspend support and secure
boot provisioning still need the development board and measurements.

## session 035 - 2026-10-06

Shortened the GP8 sensor-switch route from 19.444 mm to 15.804 mm and removed
two segments. Other routed nets and vias are unchanged. Spaced the crowded
reference labels and made the presence-switch labels read from the front.

ERC, DRC and schematic parity pass with zero violations and unconnected items.
Checked the rendered front layer. No hardware test performed.

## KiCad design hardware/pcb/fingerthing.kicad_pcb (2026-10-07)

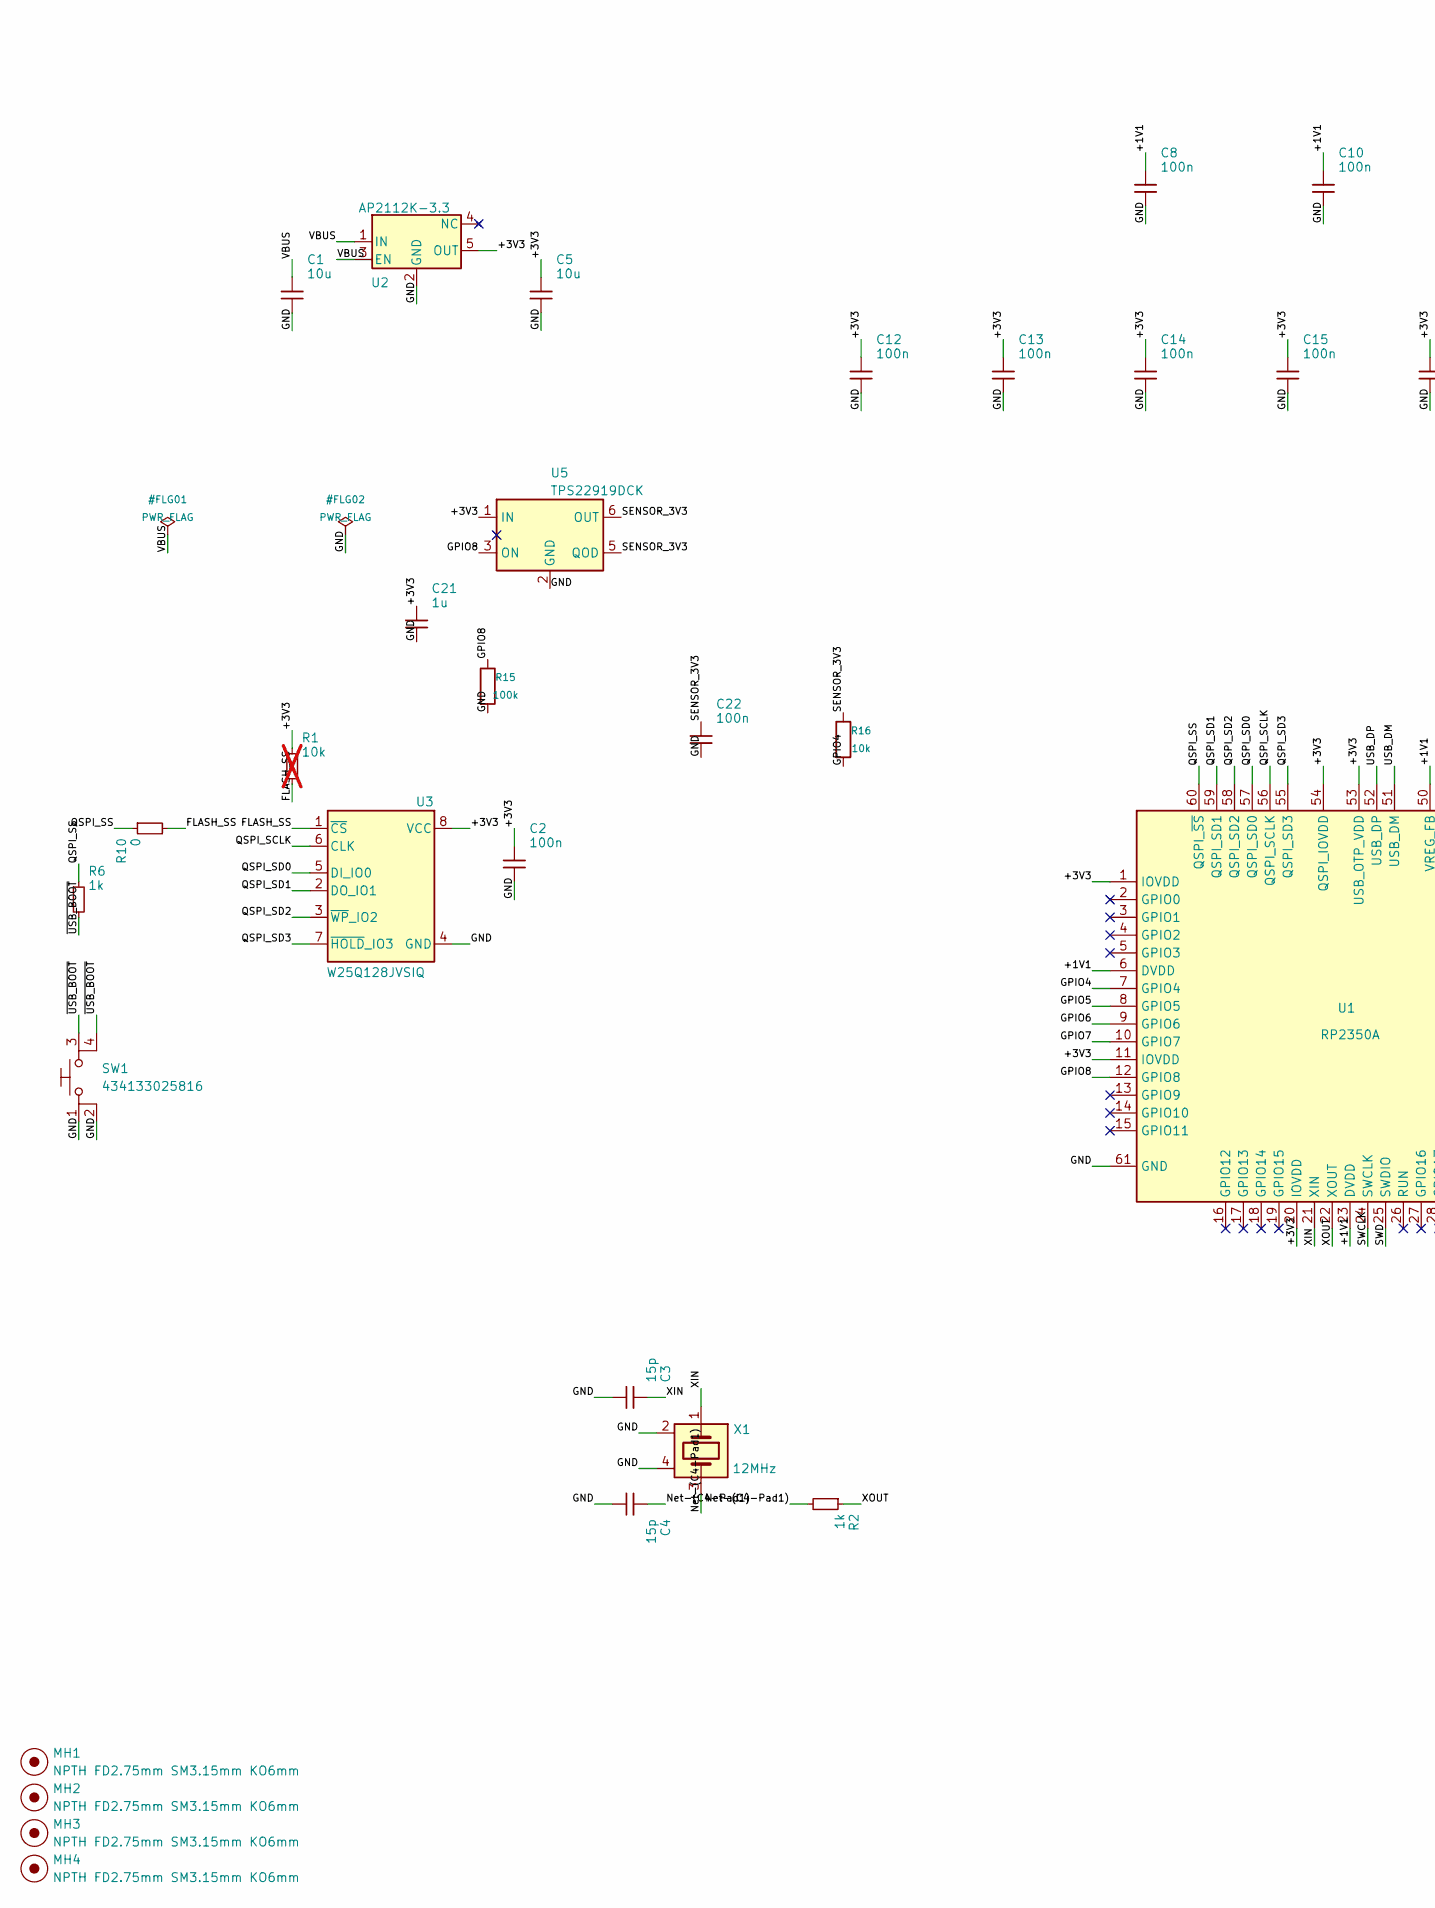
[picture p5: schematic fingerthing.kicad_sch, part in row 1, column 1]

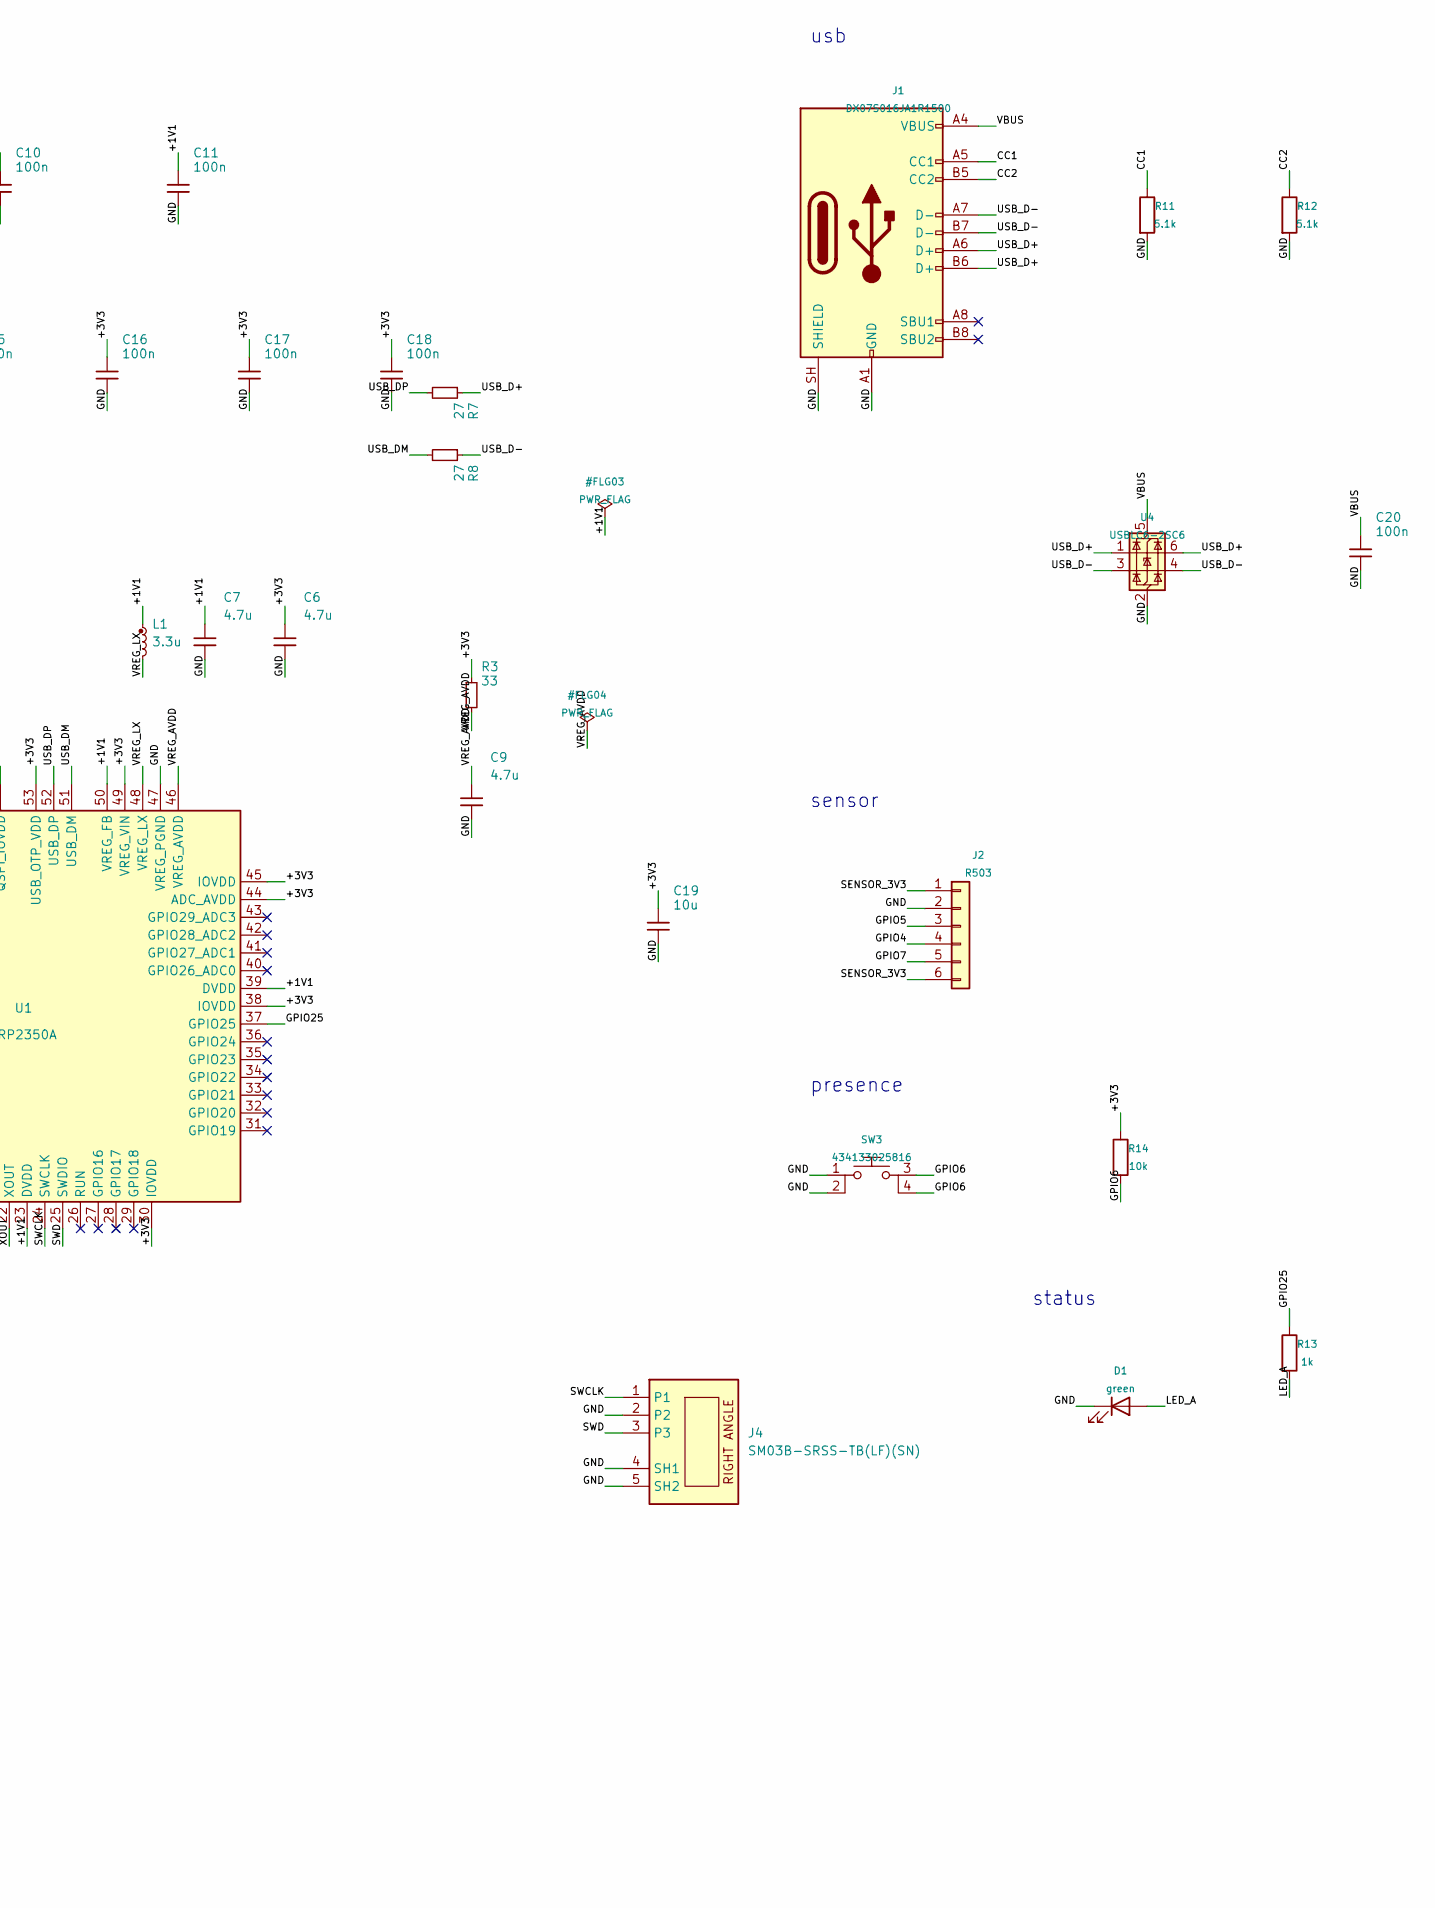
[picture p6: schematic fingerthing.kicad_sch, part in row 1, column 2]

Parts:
C1, C5, C19: 10u; generic_capc2012x125; voltage 16V; tolerance 10%; part_uid RP-01GYSK-AVBE41
C2, C8, C10, C11, C12, C13, C14, C15, C16, C17, C18, C20: 100n; generic_capc1005x50; voltage 25V; tolerance 10%; part_uid RP-01BJ9Y-KRGF41
C3, C4: 15p; generic_capc1005x50; voltage 50V; tolerance 5%; part_uid RP-01C89W-LLY9XV
C6, C7: 4.7u; generic_capc1005x50_wide; voltage 6.3V; tolerance 20%; part_uid RP-019A1P-0C2GHY
C9: 4.7u; generic_capc1005x50; voltage 6.3V; tolerance 20%; part_uid RP-019A1P-0C2GHY
C21: 1u; C_0402_1005Metric; manufacturer_pn C1005X5R1E105K050BC
C22: 100n; generic_capc1005x50; manufacturer_pn GRM155R71E104KE14D
D1: green; LED_0603_1608Metric; manufacturer_pn LTST-C190KGKT
J1: DX07S016JA1R1500; usb-c; manufacturer_pn DX07S016JA1R1500
J2: R503; JST_SH_SM06B-SRSS-TB_1x06-1MP_P1.00mm_Horizontal; manufacturer_pn SM06B-SRSS-TB(LF)(SN)
J4: SM03B-SRSS-TB(LF)(SN); jst_sm03b-srss-tb-lf--sn-; part_uid RP-01EKJ1-8V9SV1
L1: 3.3u; abracon_aota-b201610s3r3-101-t; tolerance 20%; part_uid RP-01GY5D-2VC7WP
MH1, MH2, MH3, MH4: NPTH FD2.75mm SM3.15mm KO6mm; none_mh_npth_fd2p75mm_sm3p15mm_ko6mm; part_uid RP-01HF5R-LCTEJS
R1: 10k; generic_resc1005x35; tolerance 1%; voltage 50V; part_uid RP-019A1P-53DHSX; not fitted
R2, R6: 1k; generic_resc1005x35; tolerance 1%; voltage 50V; part_uid RP-019A1P-4Z6ZWY
R3: 33; generic_resc1005x35; tolerance 1%; voltage 50V; part_uid RP-019A1P-58PW9L
R7, R8: 27; generic_resc1005x35; tolerance 1%; voltage 50V; part_uid RP-01C89V-LTEYC4
R10: 0; generic_resc1005x35; tolerance +50mR; voltage 50V; part_uid RP-019A1P-4Y4V63
R11, R12: 5.1k; R_0402_1005Metric; manufacturer_pn RC0402FR-075K1L
R13: 1k; R_0402_1005Metric; manufacturer_pn RC0402FR-071KL
R14, R16: 10k; R_0402_1005Metric; manufacturer_pn RC0402FR-0710KL
R15: 100k; R_0402_1005Metric; manufacturer_pn RC0402FR-07100KL
SW1: 434133025816; wurthelek_434133025816; part_uid RP-01H0MT-6E9H8F
SW3: 434133025816; wurthelek_434133025816; manufacturer_pn 434133025816
U1: RP2350A; rpi_rp2350a_vias; part_uid RP-01HA9H-9K5E8T
U2: AP2112K-3.3; SOT-23-5; manufacturer_pn AP2112K-3.3TRG1
U3: W25Q128JVSIQ; generic_soic127p790x195-8; voltage 2.7-3.6V; part_uid RP-01JWD4-F1H4N9
U4: USBLC6-2SC6; SOT-23-6; manufacturer_pn USBLC6-2SC6
U5: TPS22919DCK; SOT-363_SC-70-6; manufacturer_pn TPS22919DCKR
X1: 12MHz; generic_xtalcc320x250x80-4; tolerance 30ppm; part_uid RP-01G8X7-GS352B

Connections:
/+1V1: C7.1, C8.1, C10.1, C11.1, L1.1, U1.6 (DVDD), U1.23 (DVDD), U1.39 (DVDD), U1.50 (VREG_FB)
/+3V3: C2.1, C5.1, C6.1, C12.1, C13.1, C14.1, C15.1, C16.1, C17.1, C18.1, C19.1, C21.1, R1.1, R3.1, R14.1, U1.1 (IOVDD), U1.11 (IOVDD), U1.20 (IOVDD), U1.30 (IOVDD), U1.38 (IOVDD), U1.44 (ADC_AVDD), U1.45 (IOVDD), U1.49 (VREG_VIN), U1.53 (USB_OTP_VDD), U1.54 (QSPI_IOVDD), U2.5 (OUT), U3.8 (VCC), U5.1 (IN)
/CC1: J1.A5 (CC1), R11.1
/CC2: J1.B5 (CC2), R12.1
/FLASH_SS: R1.2, R10.2, U3.1 (~CS)
/GND: C1.2, C2.2, C3.2, C4.2, C5.2, C6.2, C7.2, C8.2, C9.2, C10.2, C11.2, C12.2, C13.2, C14.2, C15.2, C16.2, C17.2, C18.2, C19.2, C20.2, C21.2, C22.2, D1.1 (K), J1.A1 (GND), J1.A12 (GND), J1.B1 (GND), J1.B12 (GND), J1.SH (SHIELD), J2.2, J4.2, J4.4 (SH1), J4.5 (SH2), R11.2, R12.2, R15.2, SW1.1, SW1.2, SW3.1, SW3.2, U1.47 (VREG_PGND), U1.61 (GND), U2.2 (GND), U3.4 (GND), U4.2 (GND), U5.2 (GND), X1.2, X1.4
/GPIO4: J2.4, R16.2, U1.7 (GPIO4)
/GPIO5: J2.3, U1.8 (GPIO5)
/GPIO6: R14.2, SW3.3, SW3.4, U1.9 (GPIO6)
/GPIO7: J2.5, U1.10 (GPIO7)
/GPIO8: R15.1, U1.12 (GPIO8), U5.3 (ON)
/GPIO25: R13.1, U1.37 (GPIO25)
/LED_A: D1.2 (A), R13.2
/Net-(C4-Pad1): C4.1, R2.2, X1.3
/QSPI_SCLK: U1.56 (QSPI_SCLK), U3.6 (CLK)
/QSPI_SD0: U1.57 (QSPI_SD0), U3.5 (DI_IO0)
/QSPI_SD1: U1.59 (QSPI_SD1), U3.2 (DO_IO1)
/QSPI_SD2: U1.58 (QSPI_SD2), U3.3 (~WP_IO2)
/QSPI_SD3: U1.55 (QSPI_SD3), U3.7 (~HOLD_IO3)
/QSPI_SS: R6.1, R10.1, U1.60 (QSPI_~SS)
/SENSOR_3V3: C22.1, J2.1, J2.6, R16.1, U5.5 (QOD), U5.6 (OUT)
/SWCLK: J4.1, U1.24 (SWCLK)
/SWD: J4.3, U1.25 (SWDIO)
/USB_D+: J1.A6 (D+), J1.B6 (D+), R7.1, U4.1 (I/O1), U4.6 (I/O1)
/USB_D-: J1.A7 (D-), J1.B7 (D-), R8.1, U4.3 (I/O2), U4.4 (I/O2)
/USB_DM: R8.2, U1.51 (USB_DM)
/USB_DP: R7.2, U1.52 (USB_DP)
/VBUS: C1.1, C20.1, J1.A4 (VBUS), J1.A9 (VBUS), J1.B4 (VBUS), J1.B9 (VBUS), U2.1 (IN), U2.3 (EN), U4.5 (VBUS)
/VREG_AVDD: C9.1, R3.2, U1.46 (VREG_AVDD)
/VREG_LX: L1.2, U1.48 (VREG_LX)
/XIN: C3.1, U1.21 (XIN), X1.1
/XOUT: R2.1, U1.22 (XOUT)
/~USB_BOOT: R6.2, SW1.3, SW1.4

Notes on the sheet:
usb
sensor
presence
status

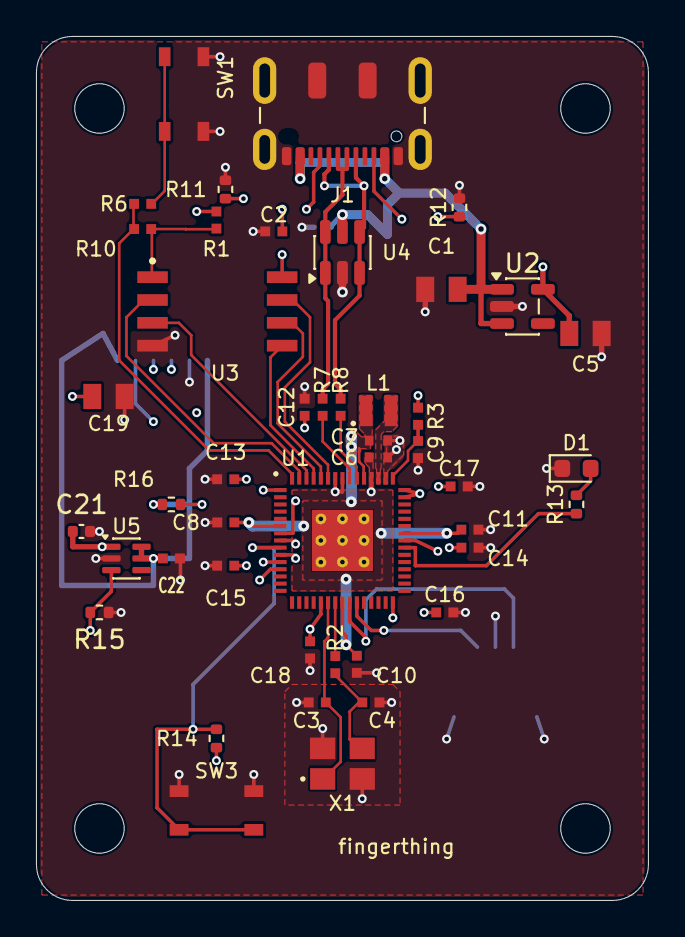
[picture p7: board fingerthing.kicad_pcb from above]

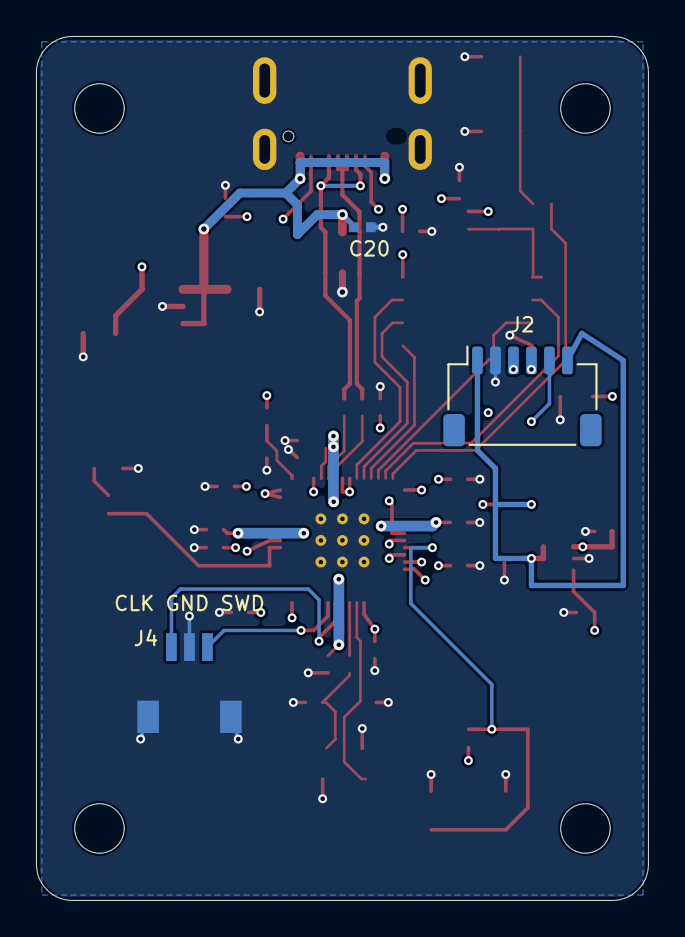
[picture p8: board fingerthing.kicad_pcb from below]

Board: 4 copper layers, 34.0 x 48.0 mm, 52 parts (3 on the bottom side), 33 nets.

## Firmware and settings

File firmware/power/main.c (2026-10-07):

#include "pico/stdlib.h"
#include "pico/low_power.h"
#include "hardware/pll.h"
#include "tusb.h"
#include <stdio.h>

static volatile bool suspended;

void tud_mount_cb(void) { suspended = false; }
void tud_umount_cb(void) { suspended = true; }
void tud_resume_cb(void) { suspended = false; }
void tud_suspend_cb(bool wake) {
    (void)wake;
    suspended = true;
}

int main(void) {
    gpio_init(8);
    gpio_put(8, false);
    gpio_set_dir(8, GPIO_OUT);
    for (unsigned pin = 4; pin <= 7; ++pin) {
        if (pin == 6) continue;
        gpio_init(pin);
        gpio_disable_pulls(pin);
    }
    stdio_init_all();
    uint32_t full = clock_get_hz(clk_sys);
    bool slow = false;
    clock_dest_bitset_t keep = clock_dest_bitset_none();
    clock_dest_bitset_add(&keep, CLK_DEST_SYS_TIMER0);
    clock_dest_bitset_add(&keep, CLK_DEST_REF_TICKS);
    for (;;) {
        uint32_t irq = save_and_disable_interrupts();
        bool sleep = suspended;
        gpio_put(8, !sleep && tud_ready());
        if (sleep != slow) {
            if (sleep) {
                uint32_t ref = clock_get_hz(clk_ref);
                clock_configure_undivided(clk_sys, CLOCKS_CLK_SYS_CTRL_SRC_VALUE_CLK_REF, 0, ref);
                clock_configure_undivided(clk_peri, 0, CLOCKS_CLK_PERI_CTRL_AUXSRC_VALUE_CLK_SYS, ref);
                pll_deinit(pll_sys);
            } else {
                set_sys_clock_khz(full / 1000, true);
            }
            slow = sleep;
        }
        if (sleep) {
            low_power_sleep_until_irq(&keep);
        }
        restore_interrupts(irq);
        if (!sleep) {
            if (getchar_timeout_us(0) == '?') printf("sys %lu\n", (unsigned long)clock_get_hz(clk_sys));
            sleep_ms(1);
        }
    }
}

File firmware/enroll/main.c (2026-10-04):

#include <stdio.h>
#include "pico/stdlib.h"
#include "pico/stdio_usb.h"
#include "enroll.h"
#include "uart.h"
#include "tusb.h"

static uint32_t start;
static volatile bool cancelled;

void tud_mount_cb(void) { cancelled = true; }
void tud_umount_cb(void) { cancelled = true; }
void tud_suspend_cb(bool wake) {
    (void)wake;
    cancelled = true;
}
void tud_cdc_line_state_cb(uint8_t itf, bool dtr, bool rts) {
    (void)itf;
    (void)rts;
    if (!dtr) cancelled = true;
}

static bool tick(void) {
    return stdio_usb_connected() && getchar_timeout_us(0) != 27 &&
        (uint32_t)(to_ms_since_boot(get_absolute_time()) - start) < 60000 && !cancelled;
}

int main(void) {
    stdio_init_all();
    sensor_off();
    sensor_tick poll = tick;
    r503 s = {sensor_io, &poll};
    for (;;) {
        while (!stdio_usb_connected()) sleep_ms(100);
        cancelled = false;
        puts("e: replace fingerprint in slot 0");
        int ch = getchar_timeout_us(60000000);
        if (ch != 'e' || cancelled || !stdio_usb_connected()) continue;
        int queued = 0;
        for (unsigned i = 0; i < 128 && !cancelled; ++i) {
            queued = getchar_timeout_us(0);
            if (queued < 0) break;
        }
        if (queued >= 0 || cancelled || !stdio_usb_connected()) continue;
        puts("replace slot 0? y");
        if (getchar_timeout_us(10000000) != 'y' || cancelled || !stdio_usb_connected()) continue;
        start = to_ms_since_boot(get_absolute_time());
        sensor_init();
        int ret = enroll(&s, tick);
        sensor_off();
        puts(ret ? "failed" : "saved");
        puts("flash the sensor firmware before use");
    }
}

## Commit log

2026-09-30 pico 2 plan / freebsd
2026-09-30 pico 2 build / button check
    Require a fresh press and release instead of accepting presence before commissioning. Check timeout, cancellation, held buttons and timer wrap against the patched function. Pin the crypto source befo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
2026-10-03 fingerprint presence gate
2026-10-04 pcb reference base
    [fingerthing.kicad_pcb, fingerthing.kicad_sch]
2026-10-04 pcb presence button
2026-10-04 usb / sensor layout
    [fingerthing.kicad_pcb, fingerthing.kicad_sch]
2026-10-04 pcb power / usb footprint
    Ground and 3.3 V routing pass DRC clearance checks. ERC and schematic parity pass. 24 unconnected items remain.
    [fingerthing.kicad_pcb, fingerthing.kicad_sch]
2026-10-04 button / led routing
    ERC and schematic parity pass. DRC has 19 unconnected items and no other violations. USB, sensor and SWD routing remain.
    [fingerthing.kicad_pcb]
2026-10-04 sensor / swd routing
    The sensor signals use In2.Cu around the core regulator routing. A rear supply bridge reconnects the 3.3 V fill. ERC and schematic parity pass. DRC has 14 unconnected USB items and no other violation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
    [fingerthing.kicad_pcb]
2026-10-04 usb power / cc routing
    Connected both VBUS banks with 0.5 mm traces and routed separate CC pull-downs. ERC and schematic parity pass. Eight USB data connections remain, with no other DRC violations.
    [fingerthing.kicad_pcb]
2026-10-04 usb data / stackup
    All PCB nets are routed. ERC, DRC and schematic parity pass with zero unconnected items and no exclusions. USB geometry follows the JLCPCB calculator result for JLC04161H-7628: 0.235 mm width, 0.15 mm pair gap and 0.25 mm ground clearance. Connector joins and ESD fan-out remain partly uncoupled and need final review.
    [fingerthing.kicad_pcb]
2026-10-04 esd bypass / sensor pinout
    Added the USBLC6-2 VBUS bypass from the ST layout example. ERC, DRC and schematic parity pass with zero unconnected items. The R503 pinout follows GROW manual 2019.6 v1.1. Its MX1.0 plug needs a veri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
    [fingerthing.kicad_pcb, fingerthing.kicad_sch]
2026-10-04 case / button fit
    [base.stl, button.stl, fingerthing.scad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]
2026-10-04 bom / usb power
    [bom.csv, fingerthing.kicad_pcb, fingerthing.kicad_sch]
2026-10-04 3v3 regulator / capacitor routing
    [bom.csv, fingerthing.kicad_pcb, fingerthing.kicad_sch]
2026-10-04 power probe
2026-10-04 sensor power prototype
2026-10-04 sensor switch / pcb
    TPS22919DCKR switches both R503 supplies from GP8. Added input and output bypass, ON pull-down and switched RX pull-up. The QOD pin uses a passive symbol type for its connection to OUT. ERC, DRC and 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
    [bom.csv, fingerthing.kicad_pcb, fingerthing.kicad_sch]
2026-10-04 sensor power / firmware
    PCB approval attempts power the R503 on GP8, wait 250 ms with cancellation available, and release UART before cutting power. Added a separate PCB enrollment image. Signing and both enrollment builds 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
2026-10-04 enrollment / usb
    Cancel enrollment prompts and attempts on USB suspend, disconnect, reconfiguration or serial DTR close. Bound queued input draining at 128 bytes. Both enrollment builds and host tests pass. Cancellat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
2026-10-04 flash lockout
    Stop after five failed multicore lockout attempts instead of erasing without an acknowledged pause. Mask interrupts for erase-only operations too. All signing builds and patched-code host tests pass. Completed writes cannot be undone by a failed resume.
    [flash.py]
2026-10-07 pin input
2026-10-07 switch routing / labels
    [fingerthing.kicad_pcb]
